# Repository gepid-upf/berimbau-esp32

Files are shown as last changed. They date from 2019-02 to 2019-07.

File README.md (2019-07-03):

# berimbau-esp32

Berimbau-like toy with gamification to aid with musical rythm and pulse education. It uses an ESP32 as it's main microcontroller. The audio is handled by the 2 DAC channels and is interrupt-based with digital mixing and SFX (muffling effect that emulates the ressonance box of the berimbau based on the distance captured by an URM37). It also uses the SPIFFS for saving the recorded sequences to be repeated by the user.

## Getting Started

### Compiling

You will need ESP-IDF to compile this. Please refer to [ESP-IDF](https://docs.espressif.com/projects/esp-idf/en/latest/get-started/index.html) to install. To compile, clone this repo recursively with all submodules, and run
```
make flash
```

### Assemblying the components

The [schematic](docs/schematic/berimbau.sch) was made using EagleCAD student version. There you can find how the components are connected. If you do not want to download EagleCAD or do not have a license, please refer to this [pdf schematic](docs/schematic/berimbau.pdf).

### Making the PCB

This is completely optional, but recommended. The PCB was made using a Roland EGX-350 router with the software CopperCAM. Please refer to the [PCB project](docs/schematic/berimbau.cam).

### Editing the Flash contents

There is a tool to edit the contents of the flash memory and dump the utilization logs. You can find it at [berimbau-tool-gui](https://github.com/gepid-upf/berimbau-tool-gui).

## Authors

* **Angelo Elias Dalzotto** - *Berimbau Interface and Game, Audio Library, URM37 driver, LED and button control* - [aedalzotto](https://github.com/aedalzotto)

## Acknowledgements

* **Boris Lovosevic** - *[ESP32_TFT_library](https://github.com/loboris/ESP32_TFT_library)* - [loboris](https://github.com/loboris)

## License

This project is licensed under the MIT License - see the [LICENSE.md](LICENSE.md) file for details.

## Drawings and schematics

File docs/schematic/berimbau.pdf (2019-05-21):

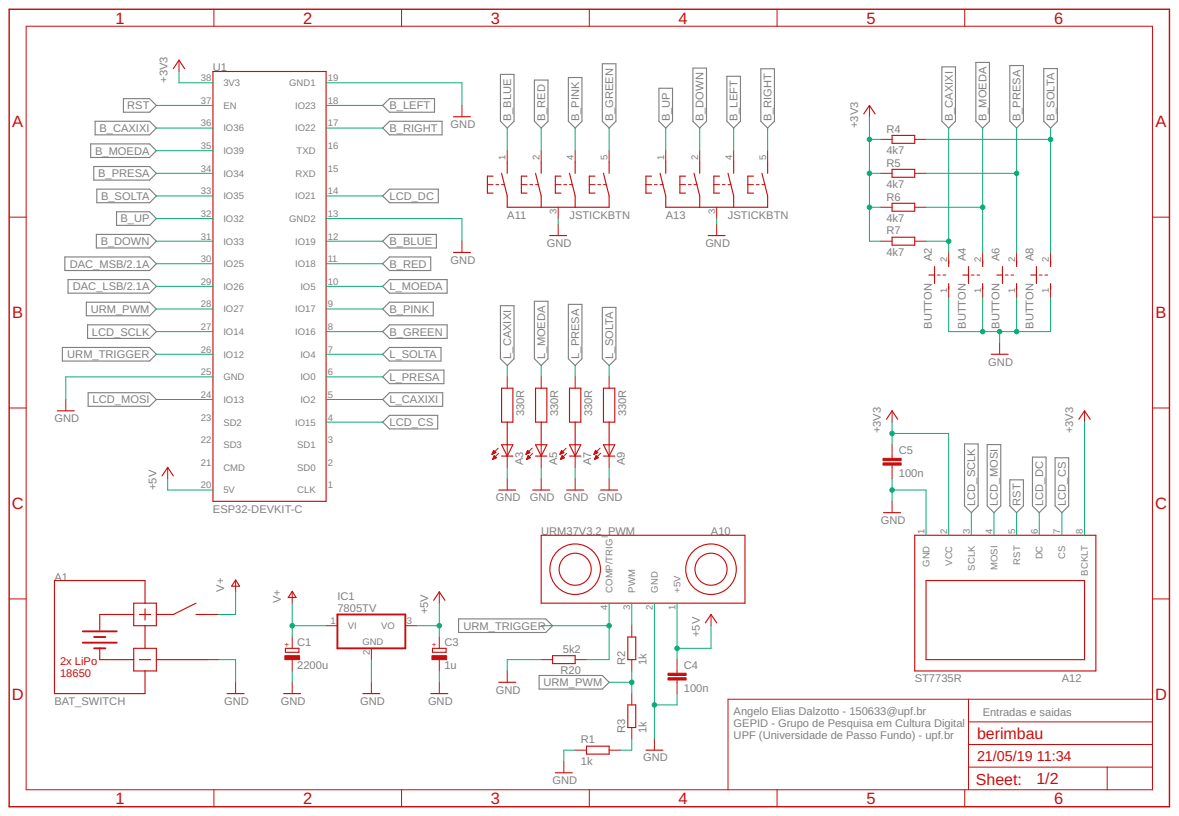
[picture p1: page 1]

GND GND

UPF (Universidade de Passo Fundo) - upf.br

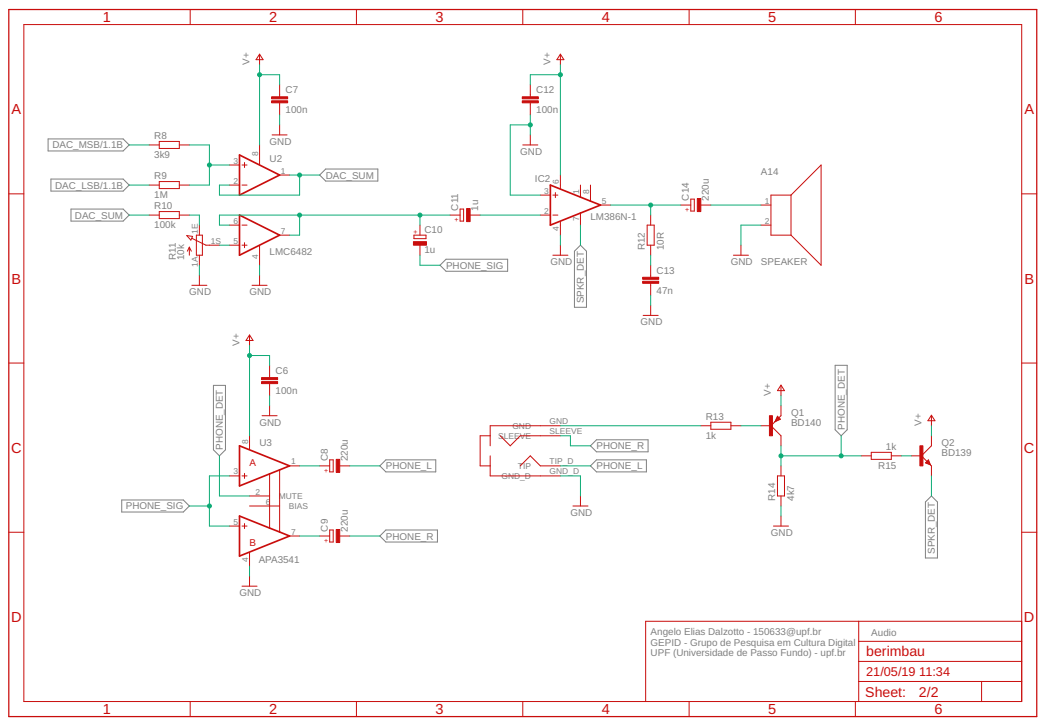
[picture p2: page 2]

Angelo Elias Dalzotto - 150633@upf.br GEPID - Grupo de Pesquisa em Cultura Digital

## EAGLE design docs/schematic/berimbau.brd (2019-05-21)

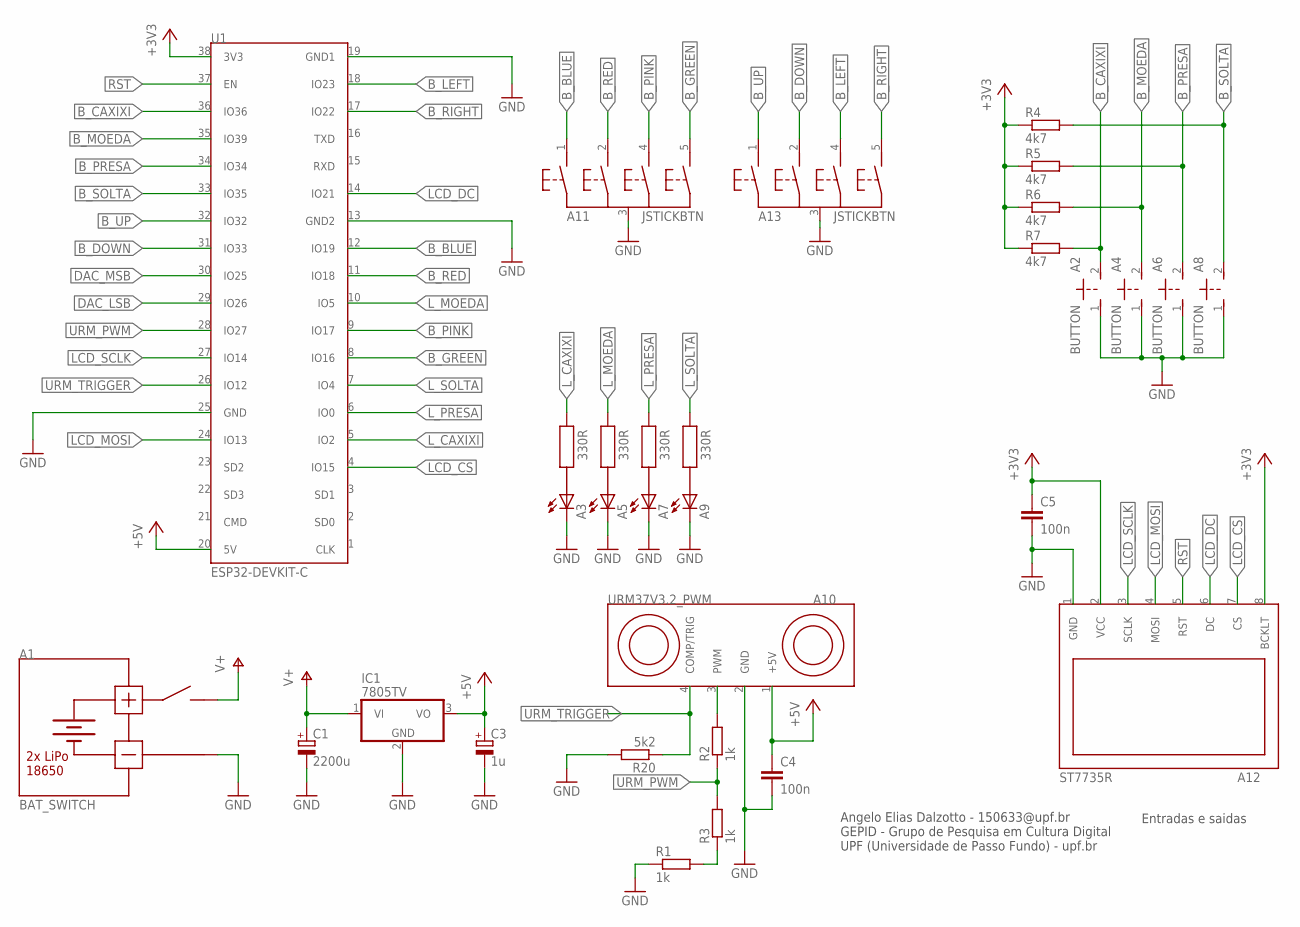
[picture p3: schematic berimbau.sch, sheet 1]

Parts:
A1: BAT_SWITCH; 1X02
A2, A4, A6, A8: BUTTON; 1X02
A3, A5, A7, A9: LED; 1X02
A10: URM37V3.2_PWM; 1X04
A11, A13: JSTICKBTN; 1X05
A12: ST7735R; 1X08
C1: 2200u; E3,5-10
C3: 1u; E2-5
C4, C5: 100n; C050-030X075
IC1: 7805TV; TO220V
R1, R2, R3: 1k; 0207/10
R4, R5, R6, R7: 4k7; 0207/10
R20: 5k2; 0207/10
U1: ESP32-DEVKIT-C; ESP32

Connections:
+3V3: A12.2 (VCC), A12.8 (BCKLT), C5.1, R4.1, R5.1, R6.1, R7.1, U1.38 (3V3)
+5V: A10.1 (+5V), C3.+, C4.1, IC1.3 (VO), U1.20 (5V)
B_BLUE: A11.1 (B1), U1.12 (IO19)
B_CAXIXI: A2.2 (S), R7.2, U1.36 (IO36)
B_DOWN: A13.2 (B2), U1.31 (IO33)
B_GREEN: A11.5 (B4), U1.8 (IO16)
B_LEFT: A13.4 (B3), U1.18 (IO23)
B_MOEDA: A4.2 (S), R6.2, U1.35 (IO39)
B_PINK: A11.4 (B3), U1.9 (IO17)
B_PRESA: A6.2 (S), R5.2, U1.34 (IO34)
B_RED: A11.2 (B2), U1.11 (IO18)
B_RIGHT: A13.5 (B4), U1.17 (IO22)
B_SOLTA: A8.2 (S), R4.2, U1.33 (IO35)
B_UP: A13.1 (B1), U1.32 (IO32)
DAC_LSB: U1.29 (IO26); also elsewhere on the board
DAC_MSB: U1.30 (IO25); also elsewhere on the board
GND: A1.2 (-), A2.1, A3.2 (C), A4.1, A5.2 (C), A6.1, A7.2 (C), A8.1, A9.2 (C), A10.2 (GND), A11.3 (COM), A12.1 (GND), A13.3 (COM), C1.-, C3.-, C4.2, C5.2, IC1.2 (GND), R1.1, R20.2, U1.13 (GND2), U1.19 (GND1), U1.25 (GND); also elsewhere on the board
LCD_CS: A12.7 (CS), U1.4 (IO15)
LCD_DC: A12.6 (DC), U1.14 (IO21)
LCD_MOSI: A12.4 (MOSI), U1.24 (IO13)
LCD_SCLK: A12.3 (SCLK), U1.27 (IO14)
L_CAXIXI: A3.1 (A), U1.5 (IO2)
L_MOEDA: A5.1 (A), U1.10 (IO5)
L_PRESA: A7.1 (A), U1.6 (IO0)
L_SOLTA: A9.1 (A), U1.7 (IO4)
unnamed: A10.3 (PWM), R2.2
unnamed: R1.2, R3.1
RST: A12.5 (RST), U1.37 (EN)
URM_PWM: R2.1, R3.2, U1.28 (IO27)
URM_TRIGGER: A10.4 (COMP/TRIG), R20.1, U1.26 (IO12)
V+: A1.1 (+), C1.+, IC1.1 (VI); also elsewhere on the board

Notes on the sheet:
Entradas e saidas
Angelo Elias Dalzotto - 150633@upf.br GEPID - Grupo de Pesquisa em Cultura Digital UPF (Universidade de Passo Fundo) - upf.br

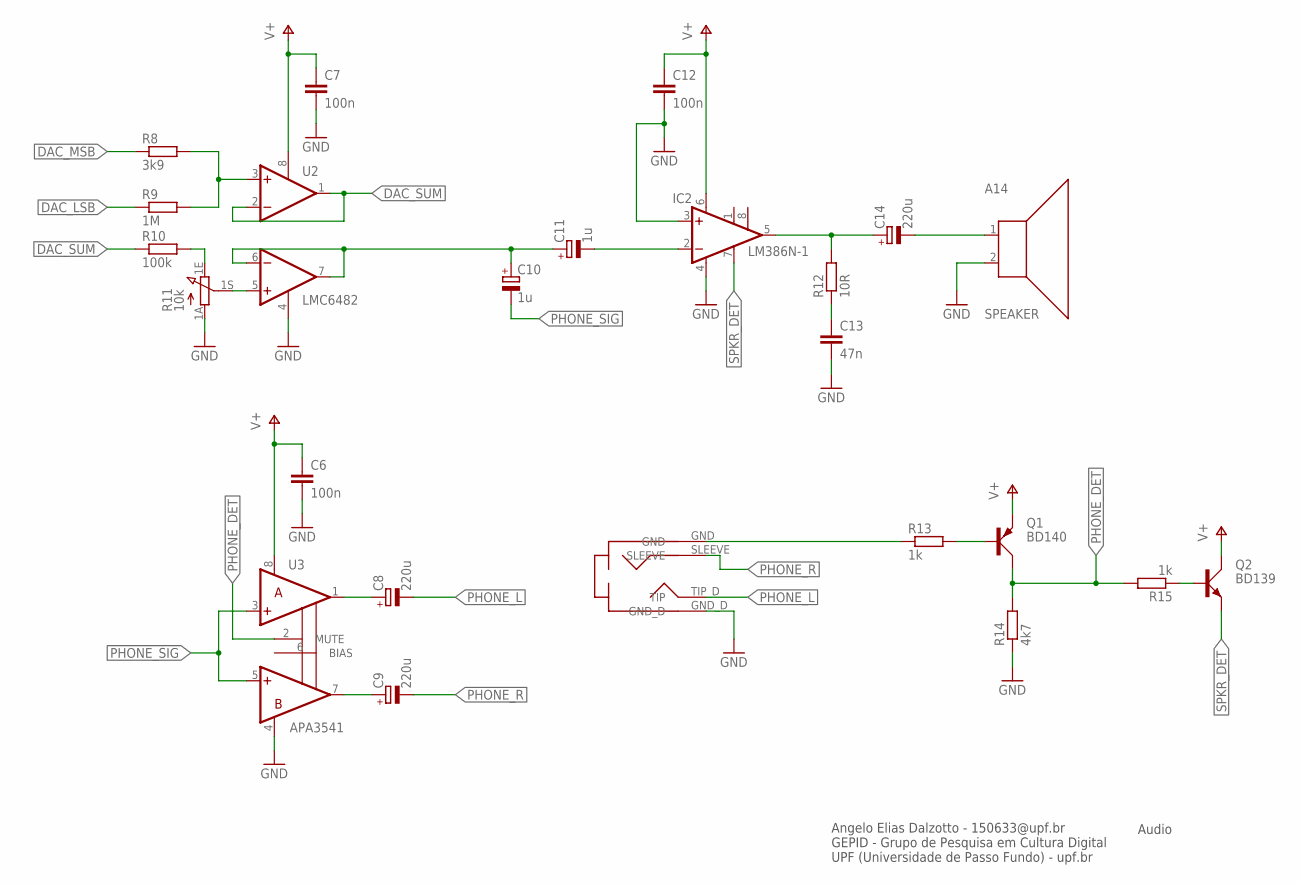
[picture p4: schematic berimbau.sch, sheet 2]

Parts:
A14: SPEAKER; 1X02
C6, C7, C12: 100n; C050-030X075
C8, C9: 220u; E2-5
C10, C11: 1u; E2-5
C13: 47n; C050-030X075
C14: 220u; E3,5-10
IC2: LM386N-1; DIL08
J1: P2_RPI; P2_RASPI
Q1: BD140; TO126AV
Q2: BD139; TO126AV
R8: 3k9; 0207/10
R9: 1M; 0207/10
R10: 100k; 0207/10
R11: 10k; PC16S
R12: 10R; 0207/10
R13, R15: 1k; 0207/10
R14: 4k7; 0207/10
U2: LMC6482; DIL08
U3: APA3541; DIL08

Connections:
DAC_LSB: R9.1; also elsewhere on the board
DAC_MSB: R8.1; also elsewhere on the board
DAC_SUM: R10.1, U2.1 (OUT_A), U2.2 (-IN_A)
GND: A14.2 (-), C6.2, C7.2, C12.2, C13.2, IC2.3 (+IN), IC2.4 (GND), J1.GND_D, R11.1A (A), R14.1, U2.4 (V-), U3.4 (GND); also elsewhere on the board
unnamed: R11.1S (S), U2.5 (+IN_B)
unnamed: C10.+, C11.+, U2.6 (-IN_B), U2.7 (OUT_B)
unnamed: R8.2, R9.2, U2.3 (+IN_A)
unnamed: R10.2, R11.1E (E)
unnamed: J1.GND, R13.1
unnamed: C14.+, IC2.5 (OUT), R12.2
unnamed: C13.1, R12.1
unnamed: A14.1 (+), C14.-
unnamed: C8.+, U3.1 (OUT_A)
unnamed: C9.+, U3.7 (OUT_B)
unnamed: Q1.B, R13.2
unnamed: Q2.B, R15.1
PHONE_DET: Q1.C, R14.2, R15.2, U3.2 (MUTE)
PHONE_L: C8.-, J1.TIP_D (TIP)
PHONE_R: C9.-, J1.SLEEVE
PHONE_SIG: C10.-, U3.3 (+IN_A), U3.5 (+IN_B)
SPKR_DET: IC2.7 (BYPASS), Q2.E
SPKR_SIG: C11.-, IC2.2 (-IN)
V+: C6.1, C7.1, C12.1, IC2.6 (VS), Q1.E, Q2.C, U2.8 (V+), U3.8 (VS1); also elsewhere on the board

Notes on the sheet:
Angelo Elias Dalzotto - 150633@upf.br GEPID - Grupo de Pesquisa em Cultura Digital UPF (Universidade de Passo Fundo) - upf.br
Audio

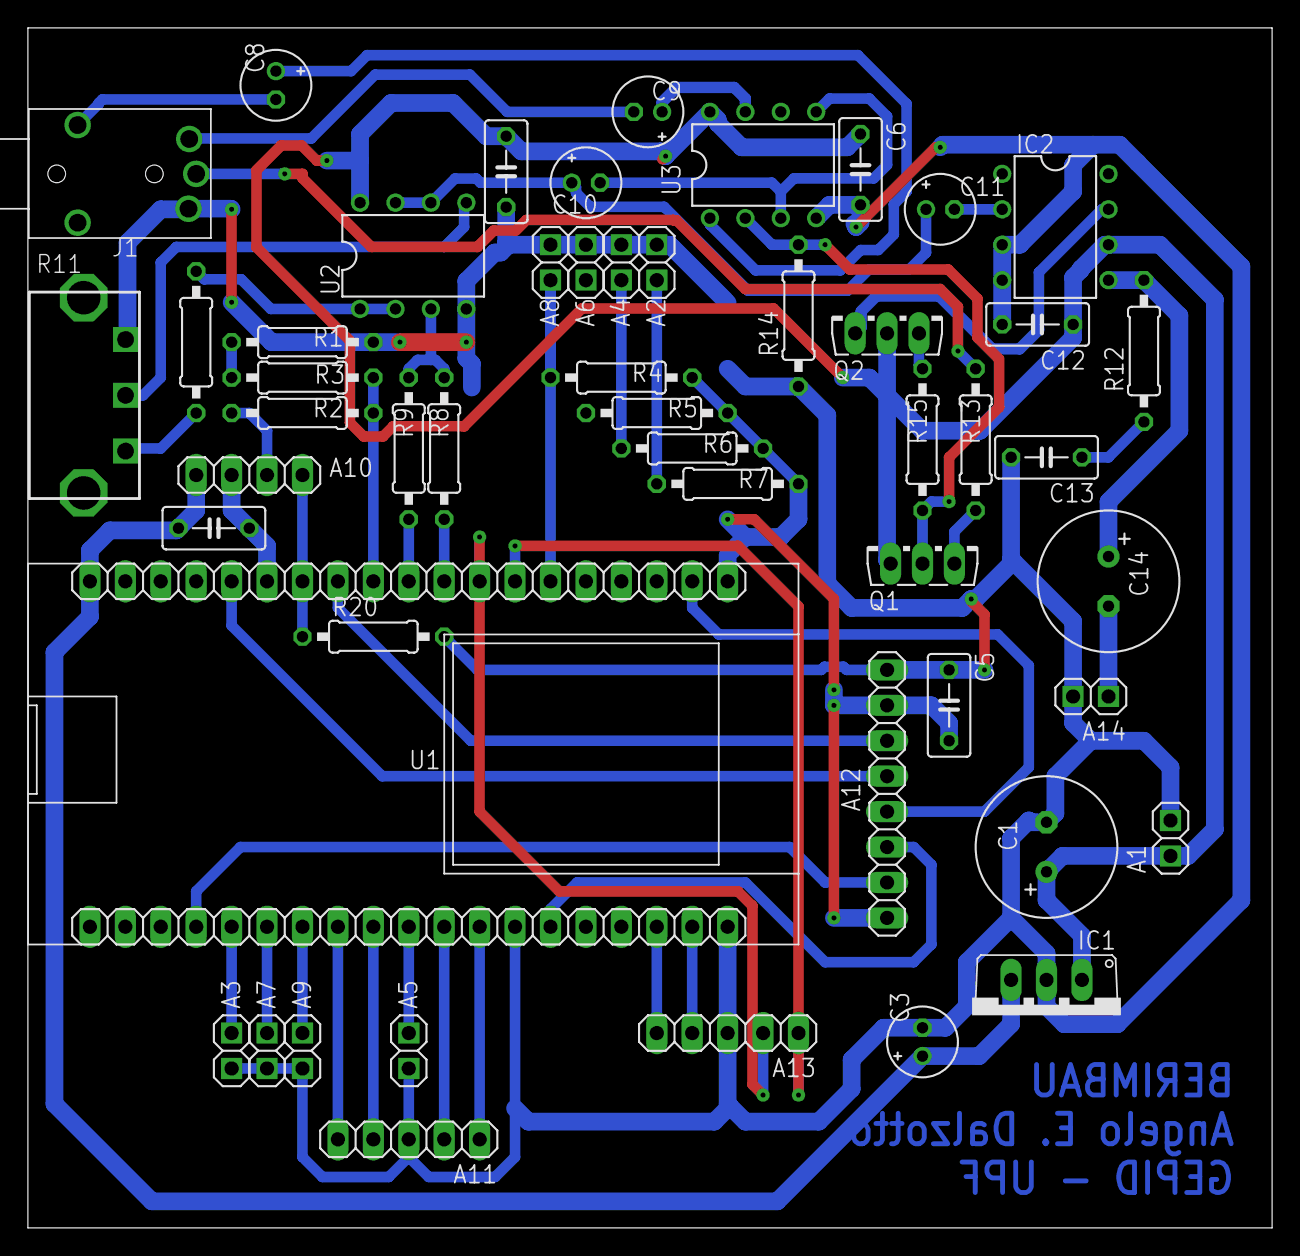
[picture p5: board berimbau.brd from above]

Board: 2 copper layers, 89.2 x 86.0 mm, 51 parts (0 on the bottom side), 50 nets.

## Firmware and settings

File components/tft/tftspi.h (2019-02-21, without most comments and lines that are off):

#define _TFTSPI_H_
#include "tftspi.h"
#include "spi_master_lobo.h"
#include "sdkconfig.h"
#include "stmpe610.h"
#define TOUCH_TYPE_NONE		0
#define TOUCH_TYPE_XPT2046	1
#define TOUCH_TYPE_STMPE610	2
#define TP_CALX_XPT2046		7472920
#define TP_CALY_XPT2046		122224794
#define TP_CALX_STMPE610	21368532
#define TP_CALY_STMPE610	11800144
#define PORTRAIT	0
#define LANDSCAPE	1
#define PORTRAIT_FLIP	2
#define LANDSCAPE_FLIP	3
#define DISP_TYPE_ILI9341	0
#define DISP_TYPE_ILI9488	1
#define DISP_TYPE_ST7789V	2
#define DISP_TYPE_ST7735	3
#define DISP_TYPE_ST7735R	4
#define DISP_TYPE_ST7735B	5
#define DISP_TYPE_ST7735G 6
#define DISP_TYPE_MAX		7
#if CONFIG_EXAMPLE_DISPLAY_TYPE == 1
#define DEFAULT_DISP_TYPE           DISP_TYPE_ST7789V
#define DEFAULT_TFT_DISPLAY_WIDTH   240
#define DEFAULT_TFT_DISPLAY_HEIGHT  320
#define DISP_COLOR_BITS_24          0x66
#define DEFAULT_GAMMA_CURVE         0
#define DEFAULT_SPI_CLOCK           26000000
#define TFT_INVERT_ROTATION         0
#define TFT_INVERT_ROTATION1        1
#define TFT_RGB_BGR                 0x00
#define USE_TOUCH	TOUCH_TYPE_NONE
#define PIN_NUM_MISO 25		// SPI MISO
#define PIN_NUM_MOSI 23		// SPI MOSI
#define PIN_NUM_CLK  19		// SPI CLOCK pin
#define PIN_NUM_CS   22		// Display CS pin
#define PIN_NUM_DC   21		// Display command/data pin
#define PIN_NUM_TCS   0		// Touch screen CS pin
#define PIN_NUM_RST  18  	// GPIO used for RESET control
#define PIN_NUM_BCKL  5     // GPIO used for backlight control
#define PIN_BCKL_ON   0     // GPIO value for backlight ON
#define PIN_BCKL_OFF  1     // GPIO value for backlight OFF
#elif CONFIG_EXAMPLE_DISPLAY_TYPE == 2
#define DEFAULT_DISP_TYPE   DISP_TYPE_ILI9341
#define DEFAULT_TFT_DISPLAY_WIDTH   240
#define DEFAULT_TFT_DISPLAY_HEIGHT  320
#define DISP_COLOR_BITS_24          0x66
#define DEFAULT_GAMMA_CURVE         0
#define DEFAULT_SPI_CLOCK           26000000
#define TFT_INVERT_ROTATION         0
#define TFT_INVERT_ROTATION1        0
#define TFT_RGB_BGR                 0x08
#define USE_TOUCH                   TOUCH_TYPE_STMPE610
#define PIN_NUM_MISO 19		// SPI MISO
#define PIN_NUM_MOSI 18		// SPI MOSI
#define PIN_NUM_CLK  5		// SPI CLOCK pin
#define PIN_NUM_CS   15		// Display CS pin
#define PIN_NUM_DC   33		// Display command/data pin
#define PIN_NUM_TCS  32		// Touch screen CS pin (NOT used if USE_TOUCH=0)
#define PIN_NUM_RST  0  	// GPIO used for RESET control (#16)
#define PIN_NUM_BCKL 0  	// GPIO used for backlight control
#define PIN_BCKL_ON  0  	// GPIO value for backlight ON
#define PIN_BCKL_OFF 1  	// GPIO value for backlight OFF
#elif CONFIG_EXAMPLE_DISPLAY_TYPE == 3
#define DEFAULT_DISP_TYPE   DISP_TYPE_ILI9341
#define DEFAULT_TFT_DISPLAY_WIDTH   320
#define DEFAULT_TFT_DISPLAY_HEIGHT  240
#define DISP_COLOR_BITS_24          0x66
#define DEFAULT_GAMMA_CURVE         0
#define DEFAULT_SPI_CLOCK           26000000
#define TFT_INVERT_ROTATION         0
#define TFT_INVERT_ROTATION1        0
#define TFT_INVERT_ROTATION2        1   // Adapte M5Stack TFT
#define TFT_RGB_BGR                 0x08
#define USE_TOUCH                   TOUCH_TYPE_NONE
#define PIN_NUM_MISO 19		// SPI MISO
#define PIN_NUM_MOSI 23		// SPI MOSI
#define PIN_NUM_CLK  18		// SPI CLOCK pin
#define PIN_NUM_CS   14		// Display CS pin
#define PIN_NUM_DC   27		// Display command/data pin
#define PIN_NUM_TCS  0		// Touch screen CS pin (NOT used if USE_TOUCH=0)
#define PIN_NUM_RST  33  	// GPIO used for RESET control (#16)
#define PIN_NUM_BCKL 32  	// GPIO used for backlight control
#define PIN_BCKL_ON  1  	// GPIO value for backlight ON
#define PIN_BCKL_OFF 0  	// GPIO value for backlight OFF
#else
#define DISP_COLOR_BITS_24	0x66
#define TFT_INVERT_ROTATION 0
#define TFT_INVERT_ROTATION1 1
#define TFT_RGB_BGR 0x08
#define PIN_NUM_MISO -1		// SPI MISO
#define PIN_NUM_MOSI 13		// SPI MOSI
#define PIN_NUM_CLK  14		// SPI CLOCK pin
#define PIN_NUM_CS   15		// Display CS pin
#define PIN_NUM_DC   21		// Display command/data pin
#define PIN_NUM_TCS  25		// Touch screen CS pin (NOT used if USE_TOUCH=0)
#define PIN_NUM_RST  0  	// GPIO used for RESET control
#define PIN_NUM_BCKL 0  	// GPIO used for backlight control
#define PIN_BCKL_ON  0  	// GPIO value for backlight ON
#define PIN_BCKL_OFF 1  	// GPIO value for backlight OFF
#define USE_TOUCH	TOUCH_TYPE_NONE
#define DEFAULT_TFT_DISPLAY_WIDTH  240
#define DEFAULT_TFT_DISPLAY_HEIGHT 320
#define DEFAULT_GAMMA_CURVE 0
#define DEFAULT_SPI_CLOCK   26000000
#define DEFAULT_DISP_TYPE   DISP_TYPE_ILI9341
#endif  // CONFIG_EXAMPLE_ESP_WROVER_KIT
extern uint8_t gray_scale;
extern uint32_t max_rdclock;
extern int _width;
extern int _height;
extern uint8_t tft_disp_type;
extern spi_lobo_device_handle_t disp_spi;
extern spi_lobo_device_handle_t ts_spi;
typedef struct __attribute__((__packed__)) {
	uint8_t r;
	uint8_t g;
	uint8_t b;
} color_t ;
#define TFT_INVOFF     0x20
#define TFT_INVONN     0x21
#define TFT_DISPOFF    0x28
#define TFT_DISPON     0x29
#define TFT_MADCTL	   0x36
#define TFT_PTLAR 	   0x30
#define TFT_ENTRYM 	   0xB7
#define TFT_CMD_NOP			0x00
#define TFT_CMD_SWRESET		0x01
#define TFT_CMD_RDDID		0x04
#define TFT_CMD_RDDST		0x09
#define TFT_CMD_SLPIN		0x10
#define TFT_CMD_SLPOUT		0x11
#define TFT_CMD_PTLON		0x12
#define TFT_CMD_NORON		0x13
#define TFT_CMD_RDMODE		0x0A
#define TFT_CMD_RDMADCTL	0x0B
#define TFT_CMD_RDPIXFMT	0x0C
#define TFT_CMD_RDIMGFMT	0x0D
#define TFT_CMD_RDSELFDIAG  0x0F
#define TFT_CMD_GAMMASET	0x26
#define TFT_CMD_FRMCTR1		0xB1
#define TFT_CMD_FRMCTR2		0xB2
#define TFT_CMD_FRMCTR3		0xB3
#define TFT_CMD_INVCTR		0xB4
#define TFT_CMD_DFUNCTR		0xB6
#define TFT_CMD_PWCTR1		0xC0
#define TFT_CMD_PWCTR2		0xC1
#define TFT_CMD_PWCTR3		0xC2
#define TFT_CMD_PWCTR4		0xC3
#define TFT_CMD_PWCTR5		0xC4
#define TFT_CMD_VMCTR1		0xC5
#define TFT_CMD_VMCTR2		0xC7
#define TFT_CMD_RDID1		0xDA
#define TFT_CMD_RDID2		0xDB
#define TFT_CMD_RDID3		0xDC
#define TFT_CMD_RDID4		0xDD
#define TFT_CMD_GMCTRP1		0xE0
#define TFT_CMD_GMCTRN1		0xE1
#define TFT_CMD_POWERA		0xCB
#define TFT_CMD_POWERB		0xCF
#define TFT_CMD_POWER_SEQ	0xED
#define TFT_CMD_DTCA		0xE8
#define TFT_CMD_DTCB		0xEA
#define TFT_CMD_PRC			0xF7
#define TFT_CMD_3GAMMA_EN	0xF2
#define ST_CMD_VCOMS       0xBB
#define ST_CMD_FRCTRL2      0xC6
#define ST_CMD_PWCTR1		0xD0
#define ST7735_FRMCTR1 0xB1
#define ST7735_FRMCTR2 0xB2
#define ST7735_FRMCTR3 0xB3
#define ST7735_INVCTR  0xB4
#define ST7735_DISSET5 0xB6
#define ST7735_PWCTR1  0xC0
#define ST7735_PWCTR2  0xC1
#define ST7735_PWCTR3  0xC2
#define ST7735_PWCTR4  0xC3
#define ST7735_PWCTR5  0xC4
#define ST7735_VMCTR1  0xC5
#define ST7735_RDID1   0xDA
#define ST7735_RDID2   0xDB
#define ST7735_RDID3   0xDC
#define ST7735_RDID4   0xDD
#define ST7735_NOP     0x00
#define ST7735_SWRESET 0x01
#define ST7735_RDDID   0x04
#define ST7735_RDDST   0x09
#define ST7735_SLPIN   0x10
#define ST7735_SLPOUT  0x11
#define ST7735_PTLON   0x12
#define ST7735_NORON   0x13
#define ST7735_PWCTR6  0xFC
#define ST7735_GMCTRP1 0xE0
#define ST7735_GMCTRN1 0xE1
#define MADCTL_MY  0x80
#define MADCTL_MX  0x40
#define MADCTL_MV  0x20
#define MADCTL_ML  0x10
#define MADCTL_MH  0x04
#define TFT_CASET		0x2A
#define TFT_PASET		0x2B
#define TFT_RAMWR		0x2C
#define TFT_RAMRD		0x2E
#define TFT_CMD_PIXFMT	0x3A
#define TFT_CMD_DELAY	0x80
static const uint8_t ST7789V_init[] = {
#if PIN_NUM_RST
  15,                   					        // 15 commands in list
#else
  16,                   					        // 16 commands in list
  TFT_CMD_SWRESET, TFT_CMD_DELAY,					//  1: Software reset, no args, w/delay
  200,												//     200 ms delay
#endif
  TFT_CMD_FRMCTR2, 5, 0x0c, 0x0c, 0x00, 0x33, 0x33,
  TFT_ENTRYM, 1, 0x45,
  ST_CMD_VCOMS, 1, 0x2B,
  TFT_CMD_PWCTR1, 1, 0x2C,
  TFT_CMD_PWCTR3, 2, 0x01, 0xff,
  TFT_CMD_PWCTR4, 1, 0x11,
  TFT_CMD_PWCTR5, 1, 0x20,
  ST_CMD_FRCTRL2, 1, 0x0f,
  ST_CMD_PWCTR1, 2, 0xA4, 0xA1,
  TFT_CMD_GMCTRP1, 14, 0xD0, 0x00, 0x05, 0x0E, 0x15, 0x0D, 0x37, 0x43, 0x47, 0x09, 0x15, 0x12, 0x16, 0x19,
  TFT_CMD_GMCTRN1, 14, 0xD0, 0x00, 0x05, 0x0D, 0x0C, 0x06, 0x2D, 0x44, 0x40, 0x0E, 0x1C, 0x18, 0x16, 0x19,
  TFT_MADCTL, 1, (MADCTL_MX | TFT_RGB_BGR),			// Memory Access Control (orientation)
  TFT_CMD_PIXFMT, 1, DISP_COLOR_BITS_24,            // *** INTERFACE PIXEL FORMAT: 0x66 -> 18 bit; 0x55 -> 16 bit
  TFT_CMD_SLPOUT, TFT_CMD_DELAY, 120,				//  Sleep out,	//  120 ms delay
  TFT_DISPON, TFT_CMD_DELAY, 120,
};
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

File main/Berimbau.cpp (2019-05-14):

/**
 * @file Berimbau.cpp
 * 
 * @author
 * Angelo Elias Dalzotto (150633@upf.br)
 * GEPID - Grupo de Pesquisa em Cultura Digital (gepid.upf.br)
 * Universidade de Passo Fundo (upf.br)
 * 
 * @copyright
 * Copyright 2018 Angelo Elias Dalzotto
 * 
 * @brief Berimbau is a digital toy to help kids with music learning.
 */

#include <freertos/FreeRTOS.h>
#include <freertos/task.h>

#include <Game.h>
#include <Interface.h>
#include <Audio.h>
#include <Button.h>
#include <Led.h>

#include "moeda.h" // Just for testing
#include "presa.h"
#include "caxixi.h"
#include "solta.h"

// Members that are added to a static vector inside the class must be initialized here.
static Button b_moeda(GPIO_NUM_39);
static Button b_caxixi(GPIO_NUM_36);
static Button b_presa(GPIO_NUM_35);
static Button b_solta(GPIO_NUM_34);

static Button b_blue(GPIO_NUM_32);
static Button b_red(GPIO_NUM_23);
static Button b_green(GPIO_NUM_22);
static Button b_pink(GPIO_NUM_33);

static Button b_left(GPIO_NUM_18);
static Button b_right(GPIO_NUM_16);
static Button b_up(GPIO_NUM_17);
static Button b_down(GPIO_NUM_19);

static Audio DRAM_ATTR a_moeda(moeda_data, moeda_length);
static Audio DRAM_ATTR a_caxixi(caxixi_data, caxixi_length, false);
static Audio DRAM_ATTR a_solta(solta_data, solta_length);
static Audio DRAM_ATTR a_presa(presa_data, presa_length);

static Led l_moeda(GPIO_NUM_4);
static Led l_caxixi(GPIO_NUM_5);
static Led l_presa(GPIO_NUM_0);
static Led l_solta(GPIO_NUM_2);

static const char* TAG = "MAIN";

extern "C" void app_main()
{
    Interface::pre_init(); // Init the LCD and the Semaphore first for loading screen

    Interface::set_button(&b_blue, Interface::Direction::D_X);
    Interface::set_button(&b_red, Interface::Direction::D_O);
    Interface::set_button(&b_green, Interface::Direction::D_T);
    Interface::set_button(&b_pink, Interface::Direction::D_S);

    Interface::set_button(&b_right, Interface::Direction::D_RIGHT);
    Interface::set_button(&b_left, Interface::Direction::D_LEFT);
    Interface::set_button(&b_up, Interface::Direction::D_UP);
    Interface::set_button(&b_down, Interface::Direction::D_DOWN);

    Game::set_button(&b_moeda, Game::Instrument::MOEDA);
    Game::set_button(&b_caxixi, Game::Instrument::CAXIXI);
    Game::set_button(&b_presa, Game::Instrument::PRESA);
    Game::set_button(&b_solta, Game::Instrument::SOLTA);

    Game::set_audio(&a_moeda, Game::Instrument::MOEDA);
    Game::set_audio(&a_caxixi, Game::Instrument::CAXIXI);
    Game::set_audio(&a_presa, Game::Instrument::PRESA);
    Game::set_audio(&a_solta, Game::Instrument::SOLTA);

    Game::set_led(&l_moeda, Game::Instrument::MOEDA);
    Game::set_led(&l_caxixi, Game::Instrument::CAXIXI);
    Game::set_led(&l_presa, Game::Instrument::PRESA);
    Game::set_led(&l_solta, Game::Instrument::SOLTA);

    xTaskCreate(Interface::task, "Interface Task", 16384, nullptr, 6, nullptr);

    Audio::init();  // TimerG0 Timer0 interrupt 44.1KHz for Audio.

    xTaskCreate(Button::task, "Button_task", 2048, nullptr, 11, nullptr);   // Updates the Button status.
    xTaskCreate(Game::task, "Game task", 8192, nullptr, 10, nullptr);
    xTaskCreate(Led::task, "LED Task", 2048, nullptr, 8, nullptr);  // Sets and updates led status
    xTaskCreate(Game::urm_task, "URM Task", 2048, nullptr, 7, nullptr); // Sets the muffle cutoff based on URM
}

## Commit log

2019-02-21 added lcd, interface and game
    [partitions.csv]
2019-02-21 added schematics
    [schematic.sch]
2019-03-14 update pins for new board
2019-03-14 added boot pull-down
    [berimbau.brd, berimbau.sch, schematic.sch]
2019-03-18 fixed pin out
2019-03-21 fixed partition table
    [partitions.csv]
2019-04-17 fixed samples and variable sizes
2019-05-14 added more logging and changed led logic
2019-05-21 removed pull down on piezo
    [berimbau.brd, berimbau.sch]
2019-05-21 create pdf schematic
